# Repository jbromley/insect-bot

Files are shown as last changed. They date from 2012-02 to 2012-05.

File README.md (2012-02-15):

Insect Bot README
=================

This repository contains code and other documents for an insect bot based on
the bot in chapter 4 of [Make: Arduino Bots and Gadgets: Six Embedded
Projects with Open Source Hardware and
Software](http://www.amazon.com/Make-Embedded-Projects-Hardware-Discovery/dp/1449389716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).

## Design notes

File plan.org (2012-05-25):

#+TITLE: Insect Bot Plan
#+AUTHOR: J. Bromley <jbromley@gmail.com>
#+DATE: February 13, 2012
#+TODO: TODO(t) IN_PROGRESS(i!) WAITING(w@/!) | DONE(d!) CANCELED(c@)

* Why?

 - Create an insect bot with some personality.
 - Use a variety of sensors.
   - light sensors
   - IR sensors
   - ultrasonic sensors
   - touch sensors
   - tilt switches
   - remote control
 - Use a variety of outputs
   - motors (obviously)
   - LED matrix
   - sound
 - Become familiar with sumbsumption architectures on Arduino/AVR.

* Outcome

The outcome for this project is an autonomous walking insect. It should be
able to avoid obstacles, either avoid or go towards light, avoid falling,
respond to sound, provide sound feedback, and be remote controlled.

* Ideas

 - When obstructed, scan for the longest free path before proceeding.
 - Add front feelers in case the bot gets to close to something for the
   ultrasonic sensor to work.
 - Add rear feelers to avoid crashing into walls while backing up.
 - Create a PCB with a bare-bones Arduino and necessary circuitry.
 - Add a third servo to pan the ultrasonic sensor left and right
 - Add a tilt switch and have the bot turn itself over if it is
   upside-down.
 - Add proximity sensors to the front legs so the bot doesn't go over
   ledges.
 - Add four photoresistors and have bot always go towards the brightest
   light. When there is no light gradient, stop.
 - Add a sound sensor and speed up briefly when there are loud sounds.
 - Add an IR receiver and use a remote control to control modes.
   * start/stop
   * light adverse vs. light seeking
   * simple control modes for directly controlling motion
 - Add logic to detect when the robot has not moved for some time due to
   an obstruction.
 - Add a Perspex or HDPE plastic shell to the back of the bot.
 - Add a piezo buzzer and emit sound to indicate events.
   * Beep a tone when obstructions are detected - higher note means
     smaller distance.
   * Beep when an IR command is received.
   * Add random chirps.
   * Beep warning tones when upside down.
   * Beep when stuck - i.e. when the robot cannot move.
 - Add a PIR sensor and move when approached.
 - Add an LED matrix "shield" that shows information about
   operation. The shield should be removable and pertinent code
   deactivated when the shield is not attached.
 - Use a LiPo battery with a charging circuit.

* Project Plan [18/48]

** Board Test
Test all components on the board to ensure their proper functioning before
trying to program all of the behaviors.
*** DONE Power supply circuit. [3/3]
    - State "DONE"       from "TODO"       [2012-04-25 Wed 21:45]
    - [X] Power switch
    - [X] LED
    - [X] Supply voltage - 5.02 V.
*** DONE Ultrasonic sensor.
    - State "DONE"       from "TODO"       [2012-04-26 Thu 23:29]
*** DONE Light sensors.
    - State "DONE"       from "TODO"       [2012-04-25 Wed 22:59]
*** DONE Buzzer.
    - State "DONE"       from "TODO"       [2012-04-26 Thu 01:14]
*** TODO IR receiver.
The IR receiver is incorrectly connected. May be able to fix it by cutting
two traces and adding three jumpers.
*** TODO Tilt switch.
*** TODO Servo control pins.

** Walking
*** IN_PROGRESS Walk straight forward with less than 5% error.
    - State "IN_PROGRESS" from "TODO"       [2012-02-23 Thu 15:40]
*** TODO Walk straight backwards with less than 5% error.
*** TODO Turn right 90 degrees.
*** TODO Turn left 90 degrees.
*** TODO Turn right 90 degrees while moving backwards.
*** TODO Turn left 90 degrees while moving backwards.
*** TODO Test to see if the bot can be made to turn in-place.
** Ultrasonic sensor
*** TODO Mount ultrasonic sensor.
*** TODO Make connection cable for sensor.
*** TODO Add object-avoidance code.
*** TODO Find sensor with most accurate response.
** Light avoidance/seeking
*** CANCELED [#C] Test an analog subtraction circuit.
    - State "CANCELED"   from "TODO"       [2012-03-13 Tue 01:32] \\
      Instead of doing light subtraction in hardware I will just use the analog 
      ports and do the comparison digitally.
*** CANCELED [#C] A digital comparison circuit based on a comparator.
    - State "CANCELED"   from "TODO"       [2012-03-13 Tue 01:32] \\
      Decided to not use a comparator to determine light direction.
*** DONE Test simple two photoresistor set up.
    - State "DONE"       from "TODO"       [2012-03-09 Fri 01:03]
Tested two photoresistors connected to Arduino analog inputs. This
configuration seems to work well enough, though the dynamic range of the
response is limited.
*** TODO Develop light-seeking/avoidance policy.
*** TODO Implement light-responsive behavior.
** Touch sensors
** Tilt sensor and self-righting
*** DONE Test tilt sensors
    - State "DONE"       from "TODO"       [2012-03-13 Tue 01:34]
Tested a two photoresistors read by two analog ports. This seems to work
well enough.
*** TODO Figure out how to right the robot from its back.
** Remote control
 ddfdf Remote control test sketch.
    - State "DONE"       from "TODO"       [2012-04-11 Wed 01:46]
*** TODO Implement mode switching in bot.
** Sound effects
*** TODO Develop mapping from actions to sound.
*** TODO Code in sound behaviors.
** PIR sensor
** Stuck detection
** Mechanical and electrical
*** TODO Make brackets for circuit board.
*** TODO Shrink wrap holding portion of brackets.
*** TODO Fix brackets to body.
*** IN_PROGRESS Circuit board for final circuitry.
    - State "IN_PROGRESS" from "TODO"       [2012-04-11 Wed 01:47]
I plan to use an Arduino Pro Mini on either a perfboard or a dedicated
etched PCB for the circuitry.
*** DONE Design power circuit.
    - State "DONE"       from "TODO"       [2012-03-16 Fri 00:57]
I am modeling my circuit after SparkFun's [[http://www.sparkfun.com/products/114][Breadboard power supply]]. I
should be able to eliminate the power jack and voltage-setting resistors
and use a 7805 instead of the LM317.

Further testing shows that the 2.5V dropout of the 7805 is not good for use
with a 9V battery. It would be better to use the L4931 LDO regulator. I will
have to check the current draw of the bot and solder an L4931 into the BBB.

I have decided to use 6 AA rechargeables to provide 7.2V. A diode will drop
this to 6.1V for direct use by the servos. The 6.1V will be fed to a LDO
regulator to drive the Arduino and other circuitry.
*** DONE Measure current draw of the bot.
    - State "DONE"       from "TODO"       [2012-03-05 Mon 22:24]
I check the bot with the normal speed gait and found it to use between 370
and 580 mA of current. The L4931 can only deliver 250 mA so it is not a
viable choice for a voltage regulator. This test was done with the DC
adapter set to provide 9V in. It nominally provides 9.13 V open-circuit and
8.38 V to 8.98 V loaded.
*** DONE Replace BBB 7805 with original L4931.
    - State "DONE"       from "TODO"       [2012-03-01 Thu 22:00]
I swapped out the 7805 for the L4931 that came with the BBB, hoping the
lower dropout voltage would give better performance but it appears the L4931
cannot source enough current (only up to 250 mA) for the robot to work
properly. I will try using the RBBB with the 7805.
*** DONE Place straight programming pins on the RBBB.
    - State "DONE"       from "TODO"       [2012-03-05 Mon 22:07]
*** CANCELED Place female header blocks on the RBBB.
    - State "CANCELED"   from "TODO"       [2012-03-05 Mon 22:08]
      I ended up not doing this because putting on female headers would obscure
      the labels for all the pins and so make it difficult to hook up any circuits.
*** DONE Make a servo connection block.
    - State "DONE"       from "TODO"       [2012-04-11 Wed 01:45]
I am using a 6-pin header for this.
*** CANCELED Build power circuit
    - State "CANCELED"   from "TODO"       [2012-04-11 Wed 01:46] \\
      The power circuit has been moved to the main circuit board.
*** TODO Investigate isolating servos from microcontroller.
*** TODO Cut down servo cables to only length necessary to reach control board.
*** TODO Make the feet stickier.
Currently the feet do not grip at all, slipping even on carpet. I need to
find a way (hot glue? building feet?) to have the feet get better traction.
*** DONE Bend PVC into a circuit board holder.
    - State "DONE"       from "TODO"       [2012-04-14 Sat 23:10]
I will just mount the board to a piece of Sintel with a set of risers.
*** TODO Make a flat plastic sheet out of polystyrene.
*** TODO Form polystyrene sheet into a circuit board holder.
*** TODO Attach battery holders to body.
I am using six 1.2 NiCad batteries to provide energy. The battery holders
for these need to be attached to the body and wired together.
*** DONE Drill holes in circuit board.
    - State "DONE"       from "TODO"       [2012-04-14 Sat 23:10]
*** DONE Place components on circuit board.
    - State "DONE"       from "TODO"       [2012-04-25 Wed 21:35]

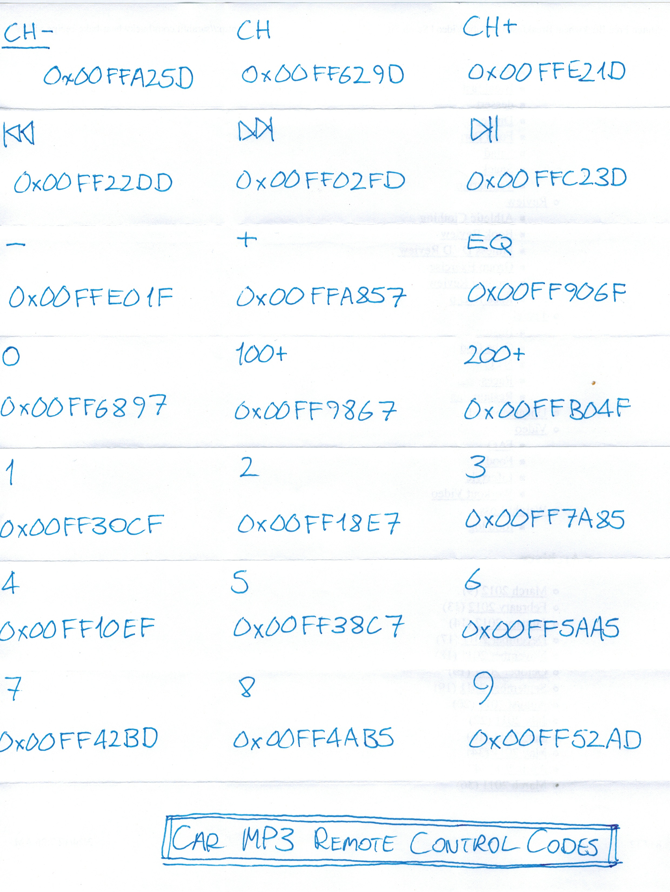
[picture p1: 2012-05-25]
doc/MP3 Remote Codes.jpeg

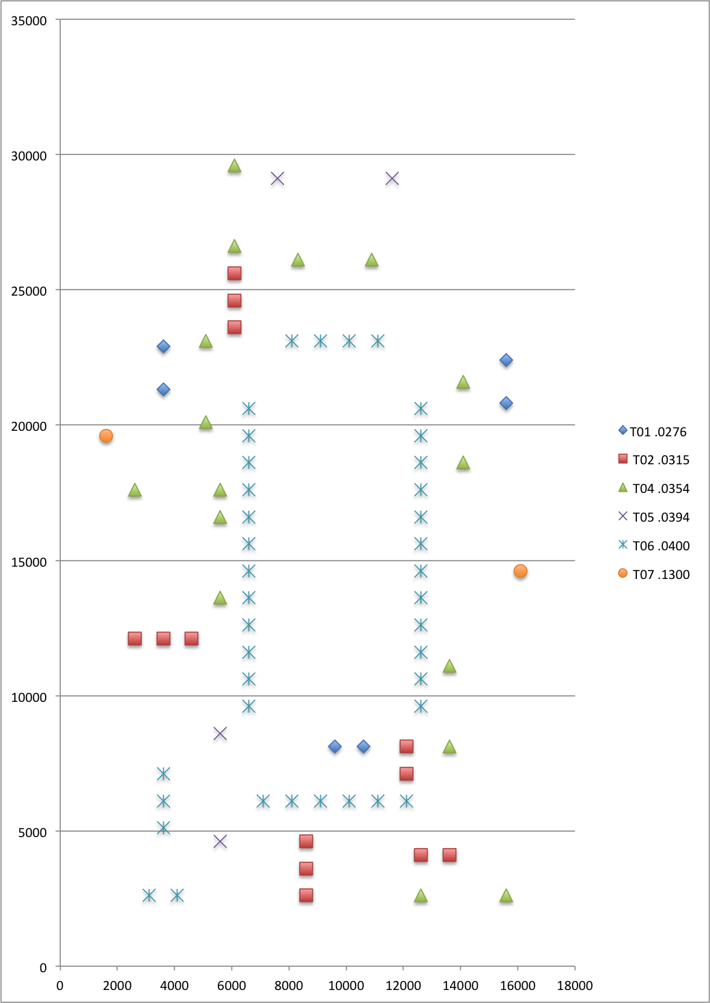
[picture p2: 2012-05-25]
doc/insect-bot-drill.png

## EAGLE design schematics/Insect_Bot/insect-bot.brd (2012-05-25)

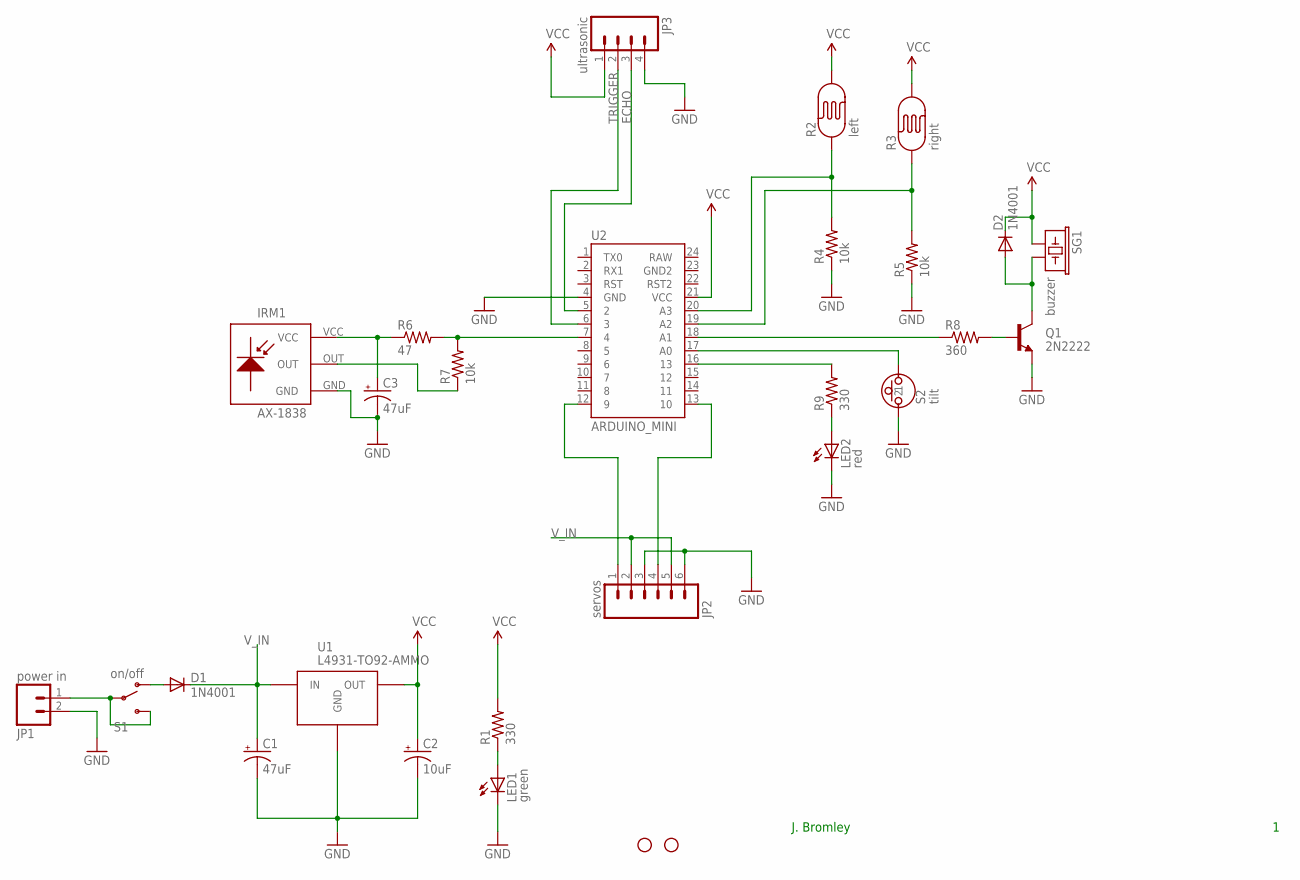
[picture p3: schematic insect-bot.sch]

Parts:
C1: 47uF; CPOL-RADIAL-10UF-25V
C2: 10uF; CPOL-RADIAL-10UF-25V
C3: 47uF; CPOL-RADIAL-100UF-25V
D1, D2: 1N4001; DIODE-1N4001
IRM1: AX-1838
JP1: power in; 1X02
JP2: servos; 1X06
JP3: ultrasonic; 1X04
JP4, JP5: STAND-OFF
LED1: green; LED3MM
LED2: red; LED3MM
Q1: 2N2222; TO-92-AMMO
R1, R9: 330; AXIAL-0.3
R2: left; PHOTOCELL
R3: right; PHOTOCELL
R4, R5, R7: 10k; AXIAL-0.3
R6: 47; AXIAL-0.3
R8: 360; AXIAL-0.3
S1: on/off; SWITCH-SPDT
S2: tilt; RADIAL-100
SG1: buzzer; BUZZER-12MM
U1: L4931-TO92-AMMO; TO-92-AMMO
U2: ARDUINO_MINI

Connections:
ECHO: JP3.3, U2.5 (2)
GND: C1.2 (-), C2.2 (-), C3.2 (-), IRM1.GND, JP1.2, JP2.3, JP2.6, JP3.4, LED1.K (C), LED2.K (C), Q1.1 (E), R4.P$1 (1), R5.P$1 (1), S2.1, U1.2 (GND), U2.4 (GND)
unnamed: JP1.1, S1.2, S1.3 (S)
unnamed: D1.A, S1.1 (O)
unnamed: LED1.A, R1.P$1 (1)
unnamed: JP2.1, U2.12 (9)
unnamed: JP2.4, U2.13 (10)
unnamed: R8.P$1 (1), U2.18 (A1)
unnamed: R3.1, R5.P$2 (2), U2.19 (A2)
unnamed: R2.1, R4.P$2 (2), U2.20 (A3)
unnamed: R6.P$2 (2), R7.P$2 (2), U2.7 (4)
unnamed: Q1.2 (B), R8.P$2 (2)
unnamed: D2.A, Q1.3 (C), SG1.- (2)
unnamed: S2.2, U2.17 (A0)
unnamed: R9.P$2 (2), U2.16 (13)
unnamed: LED2.A, R9.P$1 (1)
REMOTE: IRM1.OUT, R7.P$1 (1)
TRIGGER: JP3.2, U2.6 (3)
VCC: C2.1 (+), C3.1 (+), D2.C, IRM1.VCC, JP3.1, R1.P$2 (2), R2.2, R3.2, R6.P$1 (1), SG1.+ (1), U1.3 (OUT), U2.21 (VCC)
V_IN: C1.1 (+), D1.C, JP2.2, JP2.5, U1.1 (IN)

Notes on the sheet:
J. Bromley

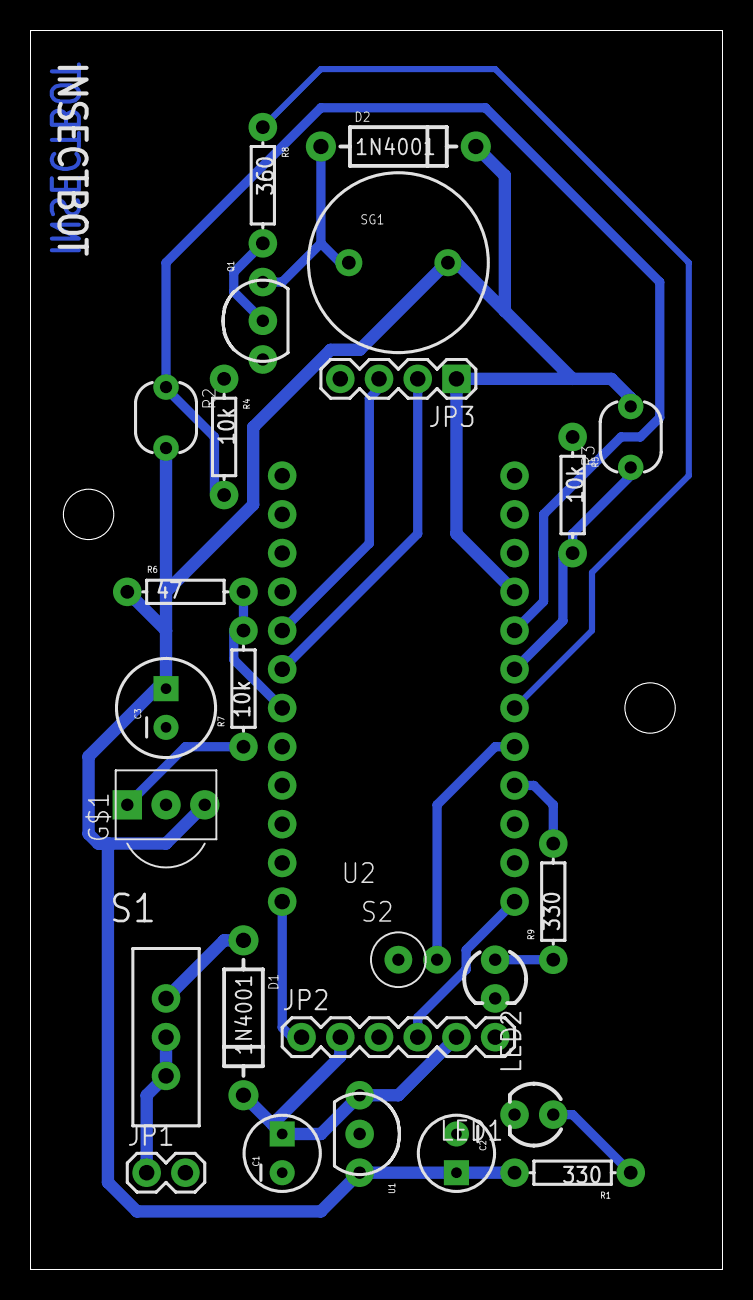
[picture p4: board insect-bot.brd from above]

Board: 2 copper layers, 45.4 x 81.3 mm, 28 parts (0 on the bottom side), 20 nets.

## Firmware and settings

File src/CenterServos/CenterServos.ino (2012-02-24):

/*
 * CenterServos.ino
 * Center both servos.
 *
 * Connections
 * D2 - front servo control
 * D3 - rear servo control
 */
#include <Servo.h>

Servo frontServo;
Servo rearServo;

int oldPosition = 90;
int frontPos = 90;
int rearPos = 90;

void setup()
{
  Serial.begin(9600);

  frontServo.attach(2);
  rearServo.attach(3);

  frontServo.write(frontPos);
  rearServo.write(rearPos);
}

void loop()
{
  oldPosition = frontPos;
  int rawValue = analogRead(A0);
  frontPos = map(rawValue, 0, 1023, 0, 180);
  rearPos = map(rawValue, 0, 1024, 180, 0);
  if (frontPos != oldPosition) {
    Serial.print(frontPos);
    Serial.print(", ");
    Serial.println(rearPos);
    frontServo.write(frontPos);
    rearServo.write(rearPos);
  }
}

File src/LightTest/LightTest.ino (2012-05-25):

/*
 * Character LCD Example Code
 * 
 * Connections
 * LCD -> Arduino
 * 4 (RS) -> D12
 * 5 (RW) -> D11
 * 6 (ENABLE) -> D10
 * Ultrasonic trigger -> D6
 * Ultrasonic echo -> D7
 * tilt switch -> D8
 * tilt indicator LED -> D9
 * red distance LED -> A2
 * yellow distance LED -> A3
 * 11 (D4) -> D5
 * 12 (D5) -> D4
 * 13 (D6) -> D3
 * 14 (D7) -> D2
 * 15 (BACKLIGHT+) -> D13
 *
 * Photoresistors
 * left -> A0
 * right -> A1

 */
#include <LiquidCrystal.h>

// LCD 
LiquidCrystal lcd(12, 11, 10, 5, 4, 3, 2);
const int backLight = 13;

// Photoresistors
const int leftSensor = A0;
const int rightSensor = A1;

// Ultrasonic sensor
const int triggerPin = 6;
const int echoPin = 7;

// Tilt switch and indicator
const int tiltSwitchPin = 8;
const int tiltLED = 9;

// Distance indicator LEDs
const int dangerLED = A2;
const int warningLED = A3;

void triggerUltrasonic()
{
  digitalWrite(triggerPin, LOW);
  delayMicroseconds(2);
  digitalWrite(triggerPin, HIGH);
  delayMicroseconds(10);
  digitalWrite(triggerPin, LOW);
}

long readDistanceCm()
{
  long echoTime = pulseIn(echoPin, HIGH);
  return echoTime < 14500 ? echoTime / 59 : -1;
}

void setup()
{
  pinMode(backLight, OUTPUT);
  pinMode(leftSensor, INPUT);
  pinMode(rightSensor, INPUT);

  pinMode(triggerPin, OUTPUT);
  pinMode(echoPin, INPUT);

  pinMode(tiltSwitchPin, INPUT);
  digitalWrite(tiltSwitchPin, HIGH);
  pinMode(tiltLED, OUTPUT);
  digitalWrite(tiltLED, LOW);

  pinMode(dangerLED, OUTPUT);
  digitalWrite(dangerLED, LOW);
  pinMode(warningLED, OUTPUT);
  digitalWrite(warningLED, LOW);

  // Turn on the backlight.
  digitalWrite(backLight, HIGH);

  // Configure the LCD interface.
  lcd.begin(20, 4);
  lcd.clear();
  lcd.setCursor(0, 0);
  lcd.print("L:");
  lcd.setCursor(8, 0);
  lcd.print("R:");
  lcd.setCursor(0, 1);
  lcd.print("Light:");
  lcd.setCursor(0, 2);
  lcd.print("Distance (cm):");
}

String padWithSpaces(const String& s, int len)
{
  String result(s);
  while (result.length() < len) {
    result += " ";
  }

  return result;
}

void display(int left, int right, long distance)
{
  String leftStr(left);
  String rightStr(right);

  leftStr = padWithSpaces(leftStr, 4);
  rightStr = padWithSpaces(rightStr, 4);

  int diff = left - right;
  lcd.setCursor(3, 0);
  lcd.print(leftStr);
  lcd.setCursor(11, 0);
  lcd.print(rightStr);

  String lightDirection;
  if (diff < -20) {
    lightDirection = "right       ";
  } else if (diff > 20) {
    lightDirection = "left        ";
  } else {
    lightDirection = "ahead/behind";
  }
  
  lcd.setCursor(7, 1);
  lcd.print(lightDirection);

  String distanceStr;
  if (distance > 0) {
    distanceStr = String(distance);
  } else {
    distanceStr = "----";
  }
  distanceStr = padWithSpaces(distanceStr, 4);
  lcd.setCursor(15, 2);
  lcd.print(distanceStr);
}

void loop()
{
  int leftLight = analogRead(A1);
  int rightLight = analogRead(A0);

  triggerUltrasonic();
  long distance = readDistanceCm();

  if (0 < distance && distance < 10) {
    digitalWrite(dangerLED, HIGH);
    digitalWrite(warningLED, LOW);
  } else if (10 < distance && distance  < 20) {
    digitalWrite(dangerLED, LOW);
    digitalWrite(warningLED, HIGH);
  } else {
    digitalWrite(dangerLED, LOW);
    digitalWrite(warningLED, LOW);
  }

    

  int tilt = digitalRead(tiltSwitchPin);
  digitalWrite(tiltLED, tilt);

  display(leftLight, rightLight, distance);
  delay(250);
}

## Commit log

2012-02-22 Added servo centering and walking sketches.
    Added a sketch that moves the servo with a potentiometer to figure
    out where the center point is. Added a sketch to test the walking
    behaviors.
2012-02-24 Added planning.
    Added planning for walking, ultrasonic sensor, and light reaction.
2012-02-24 Made sketch work both front and rear legs.
    Adjusted the sketch to move both the front and rear legs. The legs
    are moved in opposite directions.
2012-02-24 Added minicom config.
    Added a configuration to be able to talk to the Arduino serial port
    using minicom.
2012-02-25 Added power circuit schematic.
    Added a schematic for a power circuit. I can construct a smaller
    version that should work for the bot.
2012-02-25 Begin power board design.
    Added a Fritzing project with the power board design. Updated
    project plan for power board progress.
    [insect-bot-power.fzz]
2012-02-25 Initial layout of power board.
    Did an initial layout of the power board. Checked in changes before
    attempting a more compact layout.
    [insect-bot-power.fzz]
2012-02-25 Did a layout for a double-sided power board.
    [insect-bot-power.fzz]
2012-02-27 Laid out circuit.
    Changed the layout of the circuit to be produced on a two-sided board.
    [insect-bot-power.fzz]
2012-02-27 Modified plan for power and traction problems.
    I will need to make some changes to better run off of a 9V battery.
    I also need to get better traction from the feet.
2012-02-28 Added light sensor and ultrasonic tasks.
    Added tasks to test ultrasonic sensor response and a simple two
    photoresistor set up for light avoidance/seeking behavior.
2012-03-13 Added ultrasonic sensor and tilt switch.
    Added ultrasonic sensor to measure distance and two distance
    indicator LEDs. Added a tilt switch with tilt LED indicator.
2012-03-13 Updated plan progress.
    Added progress on the light-sensing circuit and tilt switch detector.
2012-03-15 Added Fritzing project for circuit design.
    Added a Fritzing project that fully describes the bot's circuitry.
    Also added Fritzing components for the HC-SR04 and the IR receiver.
    [insect-bot.fzz]
2012-03-16 Added IR receiver to Fritzing design project.
    [insect-bot.fzz]
2012-03-16 Added remote codes file.
    Added a file that details the codes sent for each button on the
    Car MP3 remote control.
2012-03-16 Completed circuit design.
2012-03-17 Rewired the IR receiver.
    Rewired the IR receiver to use the circuit recommended in the data
    sheet for the AX-1383HS. This required adding two resistors and a
    capacitor.
    [insect-bot.fzz]
2012-03-17 Added gschem symbol for the Arduino Pro Mini.
    [arduino-pro-mini.sch]
2012-03-18 Tweaks to Arduino Pro Mini.
    Added labels for the PWM pins. Removed the sch file -- symbols must
    use the extension "sym".
    [arduino-pro-mini.sch]
2012-03-18 Added Arduino Pro Mini generated symbol.
2012-03-21 Cleaned up circuit board.
    Added a custom symbol for the AX-1838HS ultrasonic sensor. General
    cleanup of the PCB.
    [insect-bot.sch]
2012-03-27 Initial version of EAGLE design files.
    I have switched from GEDA to EAGLE. These are the first iteration
    of the EAGLE design files.
    [insect-bot.brd, insect-bot.sch]
2012-03-29 First completed insect bot PCB.
    First revision with poured-copper ground plane.
    [insect-bot.brd, insect-bot.sch]
2012-03-29 Fixed some traces that were too near each other.
    [insect-bot.brd]
2012-03-29 Finished board layout.
    Spaced out close traces. Added a ground plane.
    [insect-bot.brd]
2012-04-06 Made traces thicker.
    Upped power net traces to 32 mil with 16 mil clearance and signal
    net traces to 24 mil with 16 mil clearance.
    [insect-bot.brd, insect-bot.sch]
2012-04-11 Final layout for insect bot board.
    Made traces a bit wider. Increased size of pad for the IR remote
    receiver.
    [insect-bot.brd, insect-bot.sch]
2012-04-13 Added drill file information to documentation.
    Added a spreadsheet of drill sizes and locations. Added a graphic
    showing drill hole sizes and positions.
    [insect-bot-drill.xlsx]
2012-04-26 Updated plan.
    Updated completed tasks related to the board build. Added plan items
    for testing all components on the board.
2012-05-07 Updated circuit debugging process.
2012-05-07 Added circuit test code.
    Added code that will individually test each of the sensors and
    actuators.

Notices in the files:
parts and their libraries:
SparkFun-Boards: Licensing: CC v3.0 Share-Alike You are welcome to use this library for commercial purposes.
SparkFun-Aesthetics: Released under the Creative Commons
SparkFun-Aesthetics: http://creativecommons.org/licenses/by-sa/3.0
